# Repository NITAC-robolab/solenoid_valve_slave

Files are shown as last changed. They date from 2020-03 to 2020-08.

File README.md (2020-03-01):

# 概要
電磁弁を制御するためのスレーブ．

<br>
<br>

# リポジトリ構成
```tree
├── circuit --> 回路図，基板データ
└── program --> プログラム
```

<br>
<br>

# 動作確認環境
- IDE : MPLAB X IDE v4.15
- コンパイラ : XC16 v1.41
- コンパイルオプション : -std=c99
    - File -> Project Properties -> Categories: -> Conf: [default] -> XC16(Global Options) -> xc16-gcc -> Additional options: で指定

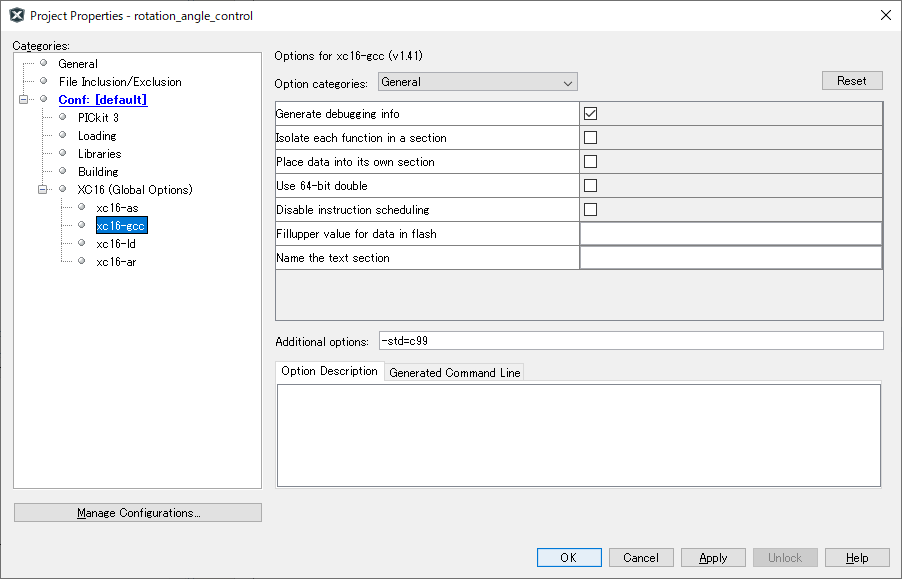
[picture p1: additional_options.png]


<br>
<br>

# 通信データ ( M->S )

| byte | 内容 |
|:-:|:--|
| 1 | ON / OFF ( 1ch ~ 8ch )|
| 2 | ON / OFF ( 9ch ~ 16ch )|

<br>
<br>

# 使用している周辺モジュール

* UART1(RX) ：Raspberry Pi との通信

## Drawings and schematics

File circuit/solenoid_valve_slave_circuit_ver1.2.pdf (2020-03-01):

## 電磁弁スレーブ ver1.2

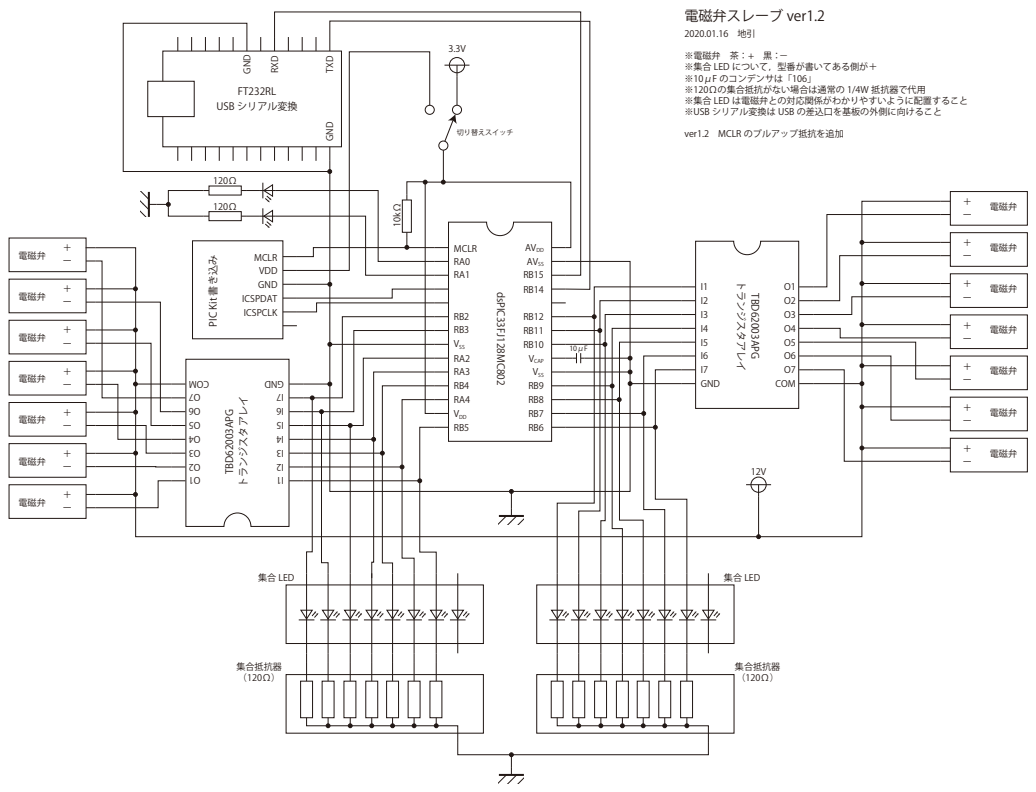
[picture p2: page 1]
FT232RL USB シリアル変換; GND; RXD; TXD; TBD62003APG; トランジスタアレイ; O1 O2 O3 O4 O5 O6 O7 COM; I1 I2 I3 I4 I5 I6 I7 GND; MCLR RA0 RA1; RB5 VDD; RA2 VSS; VCAP; RB9VSS; AVSS; AVDD; dsPIC33FJ128MC802; MCLR VDD GND ICSPDAT ICSPCLK; 切り替えスイッチ; 集合 LED; 集合抵抗器 （120Ω）

※電磁弁　茶：+　黒：－
※集合 LED について，型番が書いてある側が＋
※10μF のコンデンサは「106」
※120Ωの集合抵抗がない場合は通常の 1/4W 抵抗器で代用
※集合 LED は電磁弁との対応関係がわかりやすいように配置すること
※USB シリアル変換は USB の差込口を基板の外側に向けること
ver1.2　MCLR のプルアップ抵抗を追加

＋ー 電磁弁 ＋ー 電磁弁 ＋ー 電磁弁 ＋ー 電磁弁 ＋ー 電磁弁 ＋ー 電磁弁 ＋ー 電磁弁

PIC Kit 書き込み

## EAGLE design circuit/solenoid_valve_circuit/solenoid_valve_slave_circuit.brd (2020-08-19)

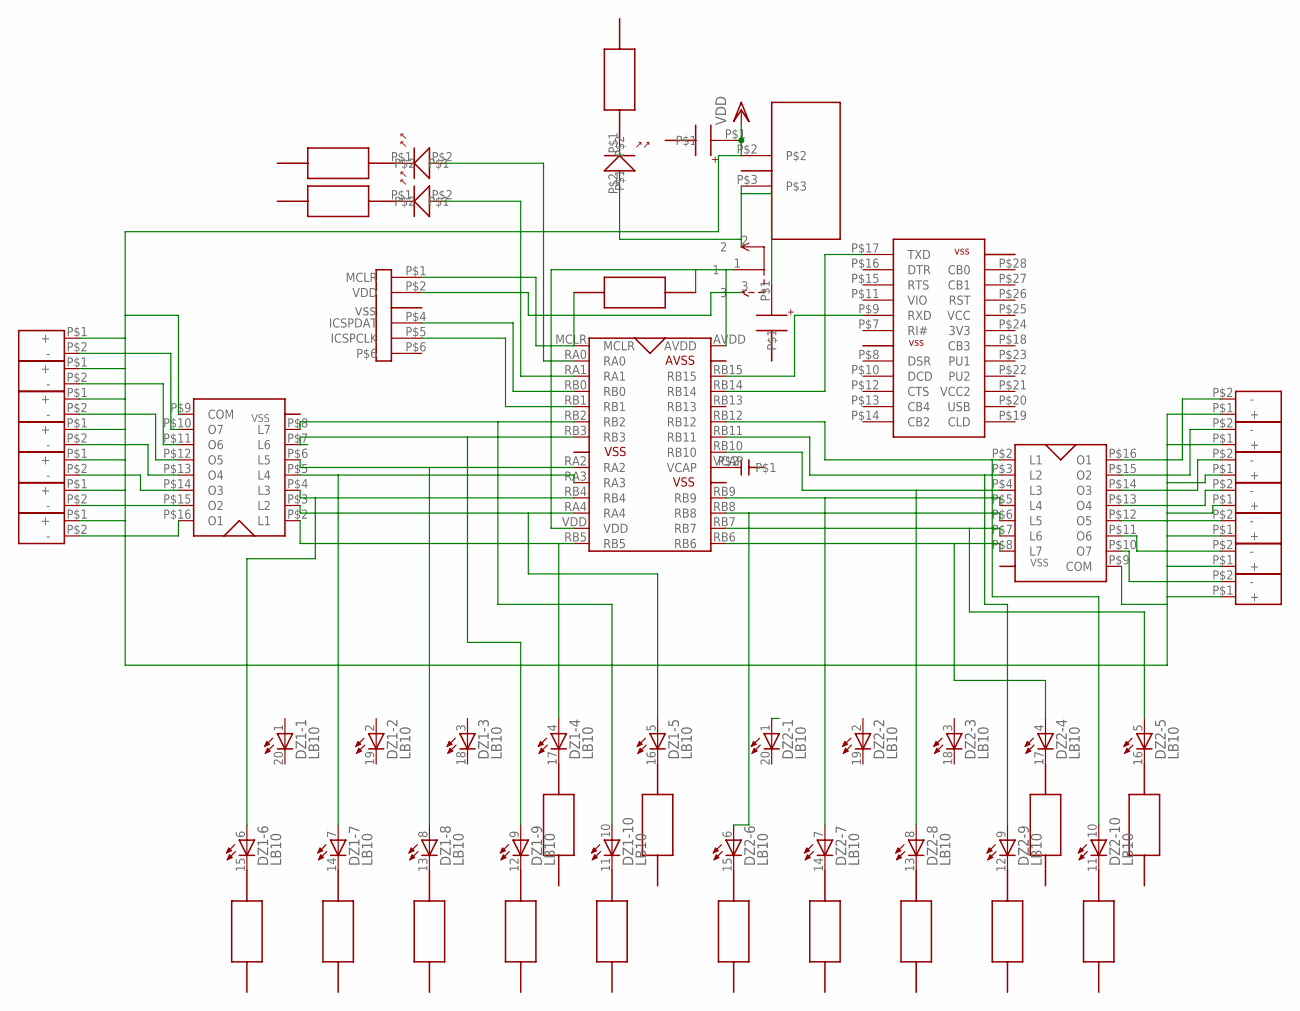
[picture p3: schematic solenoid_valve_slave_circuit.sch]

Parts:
DSPIC33FJ128MC1: DSPIC33FJ128MC; PIC_28P_2
DZ1, DZ2: LB10
SLIDE_SWITCH1: SLIDE_SWITCH_3
U$1, U$41: CAPACITOR_33
U$2, U$6, U$7, U$13, U$14, U$15, U$16, U$17, U$18, U$19, U$20, U$21, U$22, U$23, U$24, U$25, U$26, U$43: CHIP_RESISTOR
U$3: WRITER
U$4, U$5, U$42: LED
U$8, U$10: TRANSISTOR_TBD62003APG
U$9: REGULATOR
U$11: CAPACITORS_106
U$12: SERIALCOM
U$27, U$28, U$29, U$30, U$31, U$32, U$33, U$34, U$35, U$36, U$37, U$38, U$39, U$40: XHCONNECTOR_2PIN

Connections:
unnamed: SLIDE_SWITCH1.2, U$9.P$3, U$41.P$1, U$42.P$2
unnamed: DSPIC33FJ128MC1.AVDD, DSPIC33FJ128MC1.VDD, SLIDE_SWITCH1.1
unnamed: SLIDE_SWITCH1.3, U$3.P$2 (VDD)
unnamed: DSPIC33FJ128MC1.MCLR, U$3.P$1 (MCLR)
unnamed: DSPIC33FJ128MC1.RB0, U$3.P$4 (ICSPDAT)
unnamed: DSPIC33FJ128MC1.RB1, U$3.P$5 (ICSPCLK)
unnamed: DSPIC33FJ128MC1.RA0, U$4.P$2
unnamed: DSPIC33FJ128MC1.RA1, U$5.P$2
unnamed: DSPIC33FJ128MC1.RB2, DZ1.10 (A), U$8.P$8 (L7)
unnamed: DSPIC33FJ128MC1.RA3, DZ1.7 (A), U$8.P$5 (L4)
unnamed: DSPIC33FJ128MC1.RA2, DZ1.8 (A), U$8.P$6 (L5)
unnamed: DSPIC33FJ128MC1.RB3, DZ1.9 (A), U$8.P$7 (L6)
unnamed: DSPIC33FJ128MC1.RA4, DZ1.5 (A), U$8.P$3 (L2)
unnamed: DSPIC33FJ128MC1.RB5, DZ1.4 (A), U$8.P$2 (L1)
unnamed: DSPIC33FJ128MC1.RB6, DZ2.4 (A), U$10.P$8 (L7)
unnamed: DSPIC33FJ128MC1.RB7, DZ2.5 (A), U$10.P$7 (L6)
unnamed: DSPIC33FJ128MC1.RB10, DZ2.8 (A), U$10.P$4 (L3)
unnamed: DSPIC33FJ128MC1.RB11, DZ2.9 (A), U$10.P$3 (L2)
unnamed: DSPIC33FJ128MC1.RB12, DZ2.10 (A), U$10.P$2 (L1)
unnamed: DSPIC33FJ128MC1.VCAP, U$11.P$2
unnamed: DSPIC33FJ128MC1.RB15, U$12.P$9 (RXD)
unnamed: DSPIC33FJ128MC1.RB14, U$12.P$17 (TXD)
unnamed: U$10.P$10 (O7), U$38.P$2 (-)
unnamed: U$10.P$11 (O6), U$37.P$2 (-)
unnamed: U$10.P$12 (O5), U$36.P$2 (-)
unnamed: U$10.P$13 (O4), U$35.P$2 (-)
unnamed: U$8.P$10 (O7), U$33.P$2 (-)
unnamed: U$8.P$11 (O6), U$32.P$2 (-)
unnamed: U$8.P$12 (O5), U$31.P$2 (-)
unnamed: U$8.P$13 (O4), U$30.P$2 (-)
unnamed: U$8.P$14 (O3), U$29.P$2 (-)
unnamed: U$8.P$15 (O2), U$28.P$2 (-)
unnamed: U$8.P$16 (O1), U$27.P$2 (-)
unnamed: U$10.P$14 (O3), U$34.P$2 (-)
unnamed: U$10.P$15 (O2), U$39.P$2 (-)
unnamed: U$10.P$16 (O1), U$40.P$2 (-)
unnamed: DSPIC33FJ128MC1.RB9, DZ2.7 (A), U$10.P$5 (L4)
unnamed: DSPIC33FJ128MC1.RB8, DZ2.6 (A), U$10.P$6 (L5)
unnamed: DSPIC33FJ128MC1.RB4, DZ1.6 (A), U$8.P$4 (L3)
VDD: U$1.P$1, U$8.P$9 (COM), U$9.P$2, U$10.P$9 (COM), U$27.P$1 (+), U$28.P$1 (+), U$29.P$1 (+), U$30.P$1 (+), U$31.P$1 (+), U$32.P$1 (+), U$33.P$1 (+), U$34.P$1 (+), U$35.P$1 (+), U$36.P$1 (+), U$37.P$1 (+), U$38.P$1 (+), U$39.P$1 (+), U$40.P$1 (+)

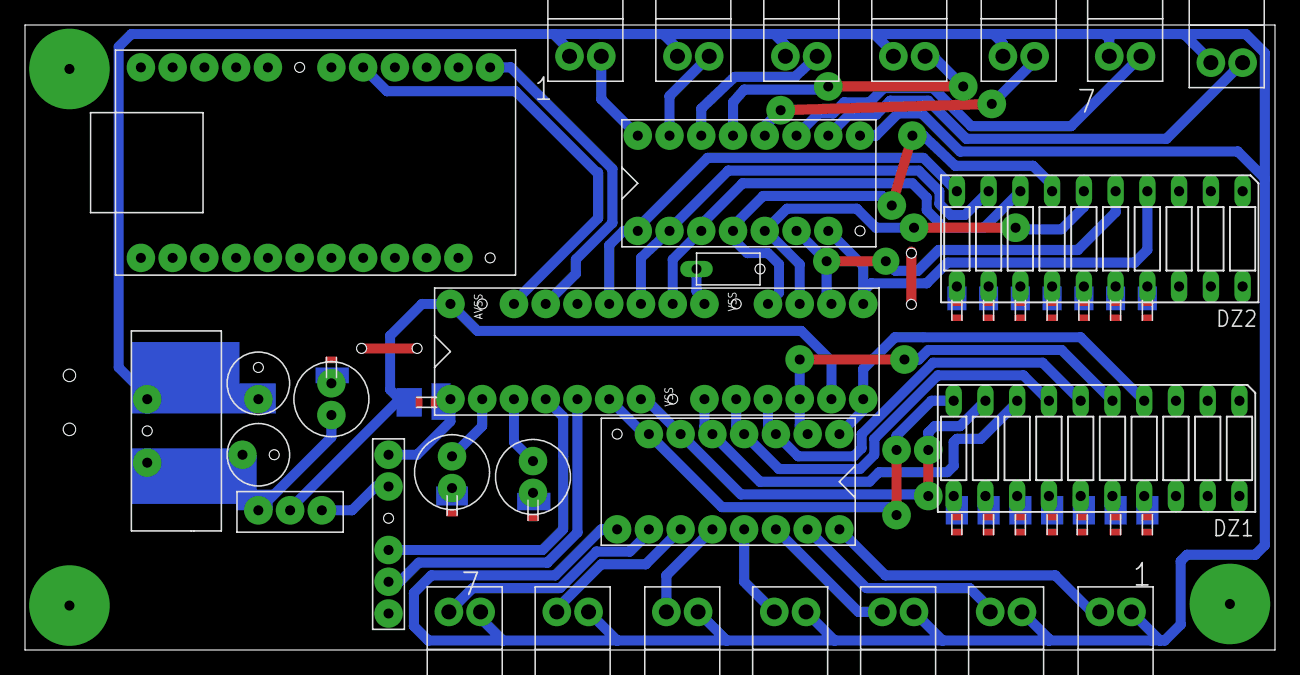
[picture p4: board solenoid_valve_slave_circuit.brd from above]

Board: 2 copper layers, 100.0 x 50.0 mm, 47 parts (0 on the bottom side), 40 nets.

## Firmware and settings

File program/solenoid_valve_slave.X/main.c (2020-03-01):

#define FCY 40000000UL /* delay 用 (Fosc/2) */
#include <libpic30.h> /* delay */
#include <stdlib.h>
#include <xc.h>
#include <math.h>
#include "Controller_Protocol.h"
#include "dsPIC33FJ128MC802_config.h"
#include "dsPIC33FJ128MC802.h"
#include "general.h"
#include "config.h"
#include "setup.h"

/*-----------------------------------------------
 *
 * main
 *
-----------------------------------------------*/
int main(int argc, char **argv)
{
    /* 初期化 */
    Initialize_Parameters();
    setup_dspic();
    setup_pin();
    setup_peripheral_module();

    uint8_t value[2] = {0, 0};

    while (1)
    {
        /* 受信 */
        Organize_Datas(RxData0, Buffer0, number_of_rxdata0, 0);
        value[0] = RxData0[0].all_data;
        value[1] = RxData0[1].all_data;

        /* 電磁弁を操作 */
        SOLENOID_VALVE_11 = (value[0] >> 0) & 1;
        SOLENOID_VALVE_12 = (value[0] >> 1) & 1;
        SOLENOID_VALVE_13 = (value[0] >> 2) & 1;
        SOLENOID_VALVE_14 = (value[0] >> 3) & 1;
        SOLENOID_VALVE_15 = (value[0] >> 4) & 1;
        SOLENOID_VALVE_16 = (value[0] >> 5) & 1;
        SOLENOID_VALVE_17 = (value[0] >> 6) & 1;
        SOLENOID_VALVE_21 = (value[1] >> 0) & 1;
        SOLENOID_VALVE_22 = (value[1] >> 1) & 1;
        SOLENOID_VALVE_23 = (value[1] >> 2) & 1;
        SOLENOID_VALVE_24 = (value[1] >> 3) & 1;
        SOLENOID_VALVE_25 = (value[1] >> 4) & 1;
        SOLENOID_VALVE_26 = (value[1] >> 5) & 1;
        SOLENOID_VALVE_27 = (value[1] >> 6) & 1;

        /* 動作周期調整 */
        __delay_ms(5);
    }
    return (EXIT_SUCCESS);
}

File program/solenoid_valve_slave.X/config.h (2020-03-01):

#ifndef CONFIG_H
#define CONFIG_H

#define USE_LOAD_PARAM false
#define USE_OPERATE_MOTOR false

/*-----------------------------------------------
 *
 * 電磁弁
 *
-----------------------------------------------*/
#define SOLENOID_VALVE_11 LATB12
#define SOLENOID_VALVE_12 LATB11
#define SOLENOID_VALVE_13 LATB10
#define SOLENOID_VALVE_14 LATB9
#define SOLENOID_VALVE_15 LATB8
#define SOLENOID_VALVE_16 LATB7
#define SOLENOID_VALVE_17 LATB6
#define SOLENOID_VALVE_21 LATB2
#define SOLENOID_VALVE_22 LATB3
#define SOLENOID_VALVE_23 LATA2
#define SOLENOID_VALVE_24 LATA3
#define SOLENOID_VALVE_25 LATB4
#define SOLENOID_VALVE_26 LATA4
#define SOLENOID_VALVE_27 LATB5

/*-----------------------------------------------
 *
 * デバッグ
 *
-----------------------------------------------*/
#define DEBUG_LED_1 LATA0
#define DEBUG_LED_2 LATA1

#endif

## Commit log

2020-01-14 pwm_control からプログラムをコピーしてきた．
    ◍ 通信ができることを確認．
2020-03-01 動作確認完了
    commit 5ceaa4b08a21eab67eb7516fd90b9855c94893c7
    Author: Takuto Jibiki <eipuuuuk825@gmail.com>
    Date: Sun Mar 1 12:11:20 2020 +0900
    [地引] README を追加
    commit 90dbaa48f151ba28be088cb7c352ae35e69c4bc8
    Author: Takuto Jibiki <eipuuuuk825@gmail.com>
    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
2020-08-19 eagleの基板データを追加
    eagleの基板データを修正
    ・コネクタの間隔をあけた
    ・それに伴うパターンの変更
    ・出力データの削除
    [solenoid_valve_slave_circuit.brd, solenoid_valve_slave_circuit.sch]
